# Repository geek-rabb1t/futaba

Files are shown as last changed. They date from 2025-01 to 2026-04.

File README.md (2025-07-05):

# Futaba

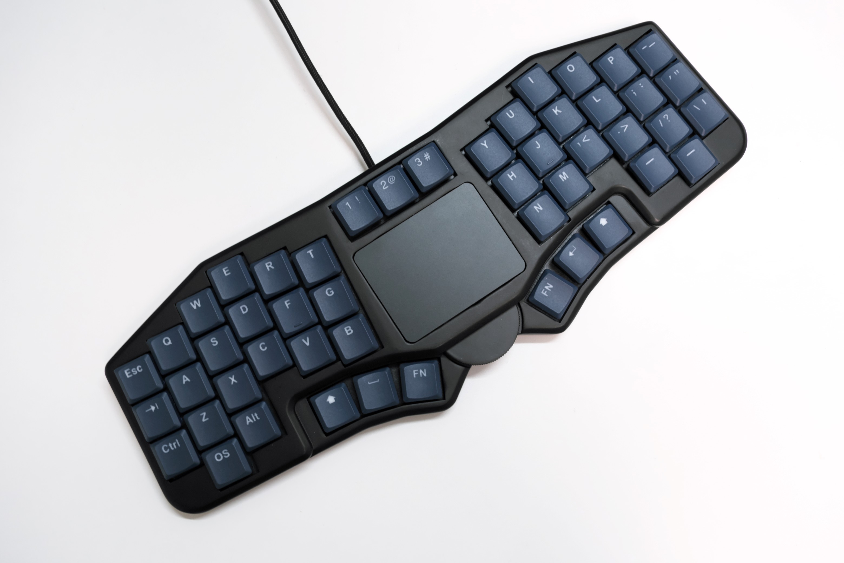
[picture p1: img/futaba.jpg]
Futaba


Futaba is a keyboard with trackpad.

## Features

- One-step-down thumb cluster that reduces fatigue even after long hours of work.
- Trackpad with multi-touch support for up to four fingers.
- Clickable giant wheel.
- Stack-mounted and flex-cut for the same feel on every key.
- Cable guides for easy use in tight spaces.

## Directory structure

This repository contains hardware design data only.

- Cases
    - 3D data of cases designed with FreeCAD.
    - It also contains stl files.
- Forms
    - Cut data of forms designed in Affinity Designer that can be ordered from Yousha Kobo.
- PCB
    - PCB data designed by KiCAD.

## About Firmware

QMK firmware or Vial firmware can be obtained from the following URL

- QMK Firmware
  - https://github.com/geek-rabb1t/qmk_firmware/tree/futaba
- Vial
  - https://github.com/geek-rabb1t/vial-qmk/tree/gr_master/keyboards/geek_rabb1t/futaba

## Build Guide

Please read here.

- https://geek-rabb1t.github.io/futaba/build_guide

---

# Futaba

Futaba

Futabaはトラックパッド付きキーボードです。

## 特徴

- 長時間の作業でも疲れにくい、一段下がった親指クラスタ。
- 4本指までのマルチタッチに対応したトラックパッド。
- クリック可能な巨大ホイール。
- スタックマウントとフレックスカットにより、どのキーも同じ打鍵感。
- 狭い場所でも使いやすいケーブルガイド。

## ディレクトリ構造

このリポジトリにはハードウェアの設計データのみ格納しています。

- case
    - FreeCADで設計したケースの3Dデータ。
    - stlファイルも含まれます。
- form
    - Affinity designerで設計した遊舎工房に発注可能なFormのカットデータ。
- pcb
    - KiCADで設計したPCBデータ。

## ファームウェアについて

以下のURLにQMK Firmwareもしくは、 Vialのファームウェアがあります。

- QMK Firmware
  - https://github.com/geek-rabb1t/qmk_firmware/tree/futaba
- Vial
  - https://github.com/geek-rabb1t/vial-qmk/tree/gr_master/keyboards/geek_rabb1t/futaba

## 組み立て手順

こちらをご覧ください。

- https://geek-rabb1t.github.io/futaba/build_guide

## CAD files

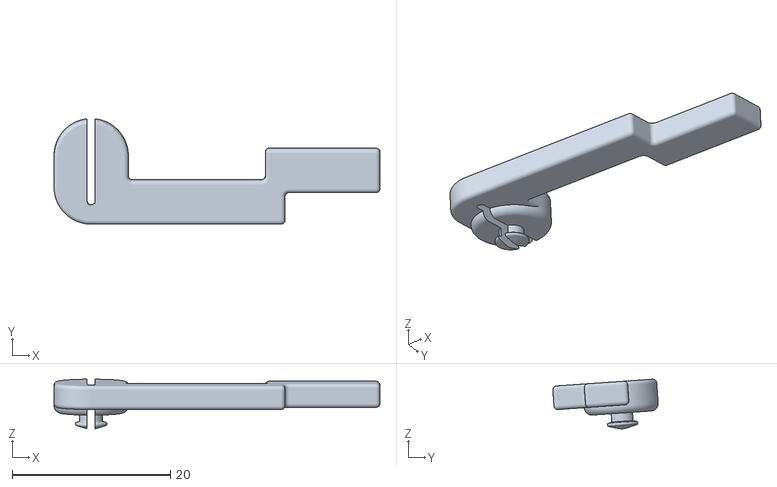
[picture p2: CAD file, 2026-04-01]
case/export/futaba-clicker_fdm.stl
41.2 x 13.3 x 6.27

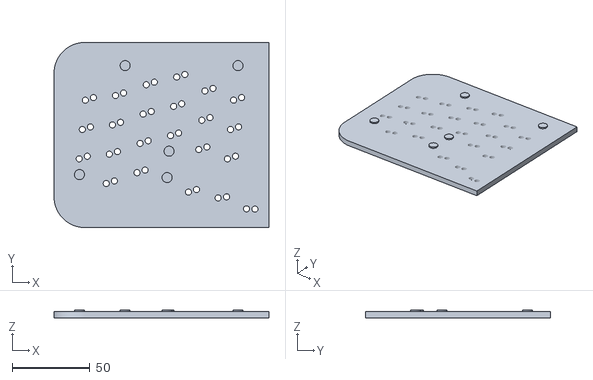
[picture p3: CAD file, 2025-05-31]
jig/soldering-jig-left-side.stl
138.6 x 119.4 x 5.00

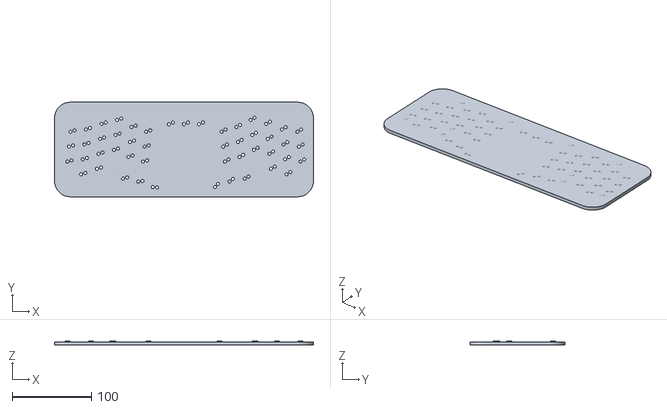
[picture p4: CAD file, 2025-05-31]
jig/soldering-jig-integrated.stl
327.0 x 119.4 x 5.00

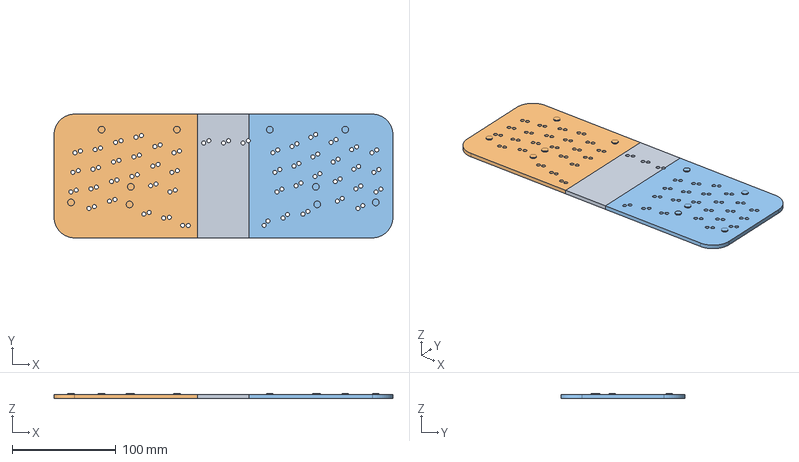
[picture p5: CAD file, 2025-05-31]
jig/soldering-jig.FCStd
327.0 x 119.4 x 5.00 mm
integrated
left-side
right-side

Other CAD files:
case/futaba-clicker.FCStd
jig/soldering-jig-right-side.stl

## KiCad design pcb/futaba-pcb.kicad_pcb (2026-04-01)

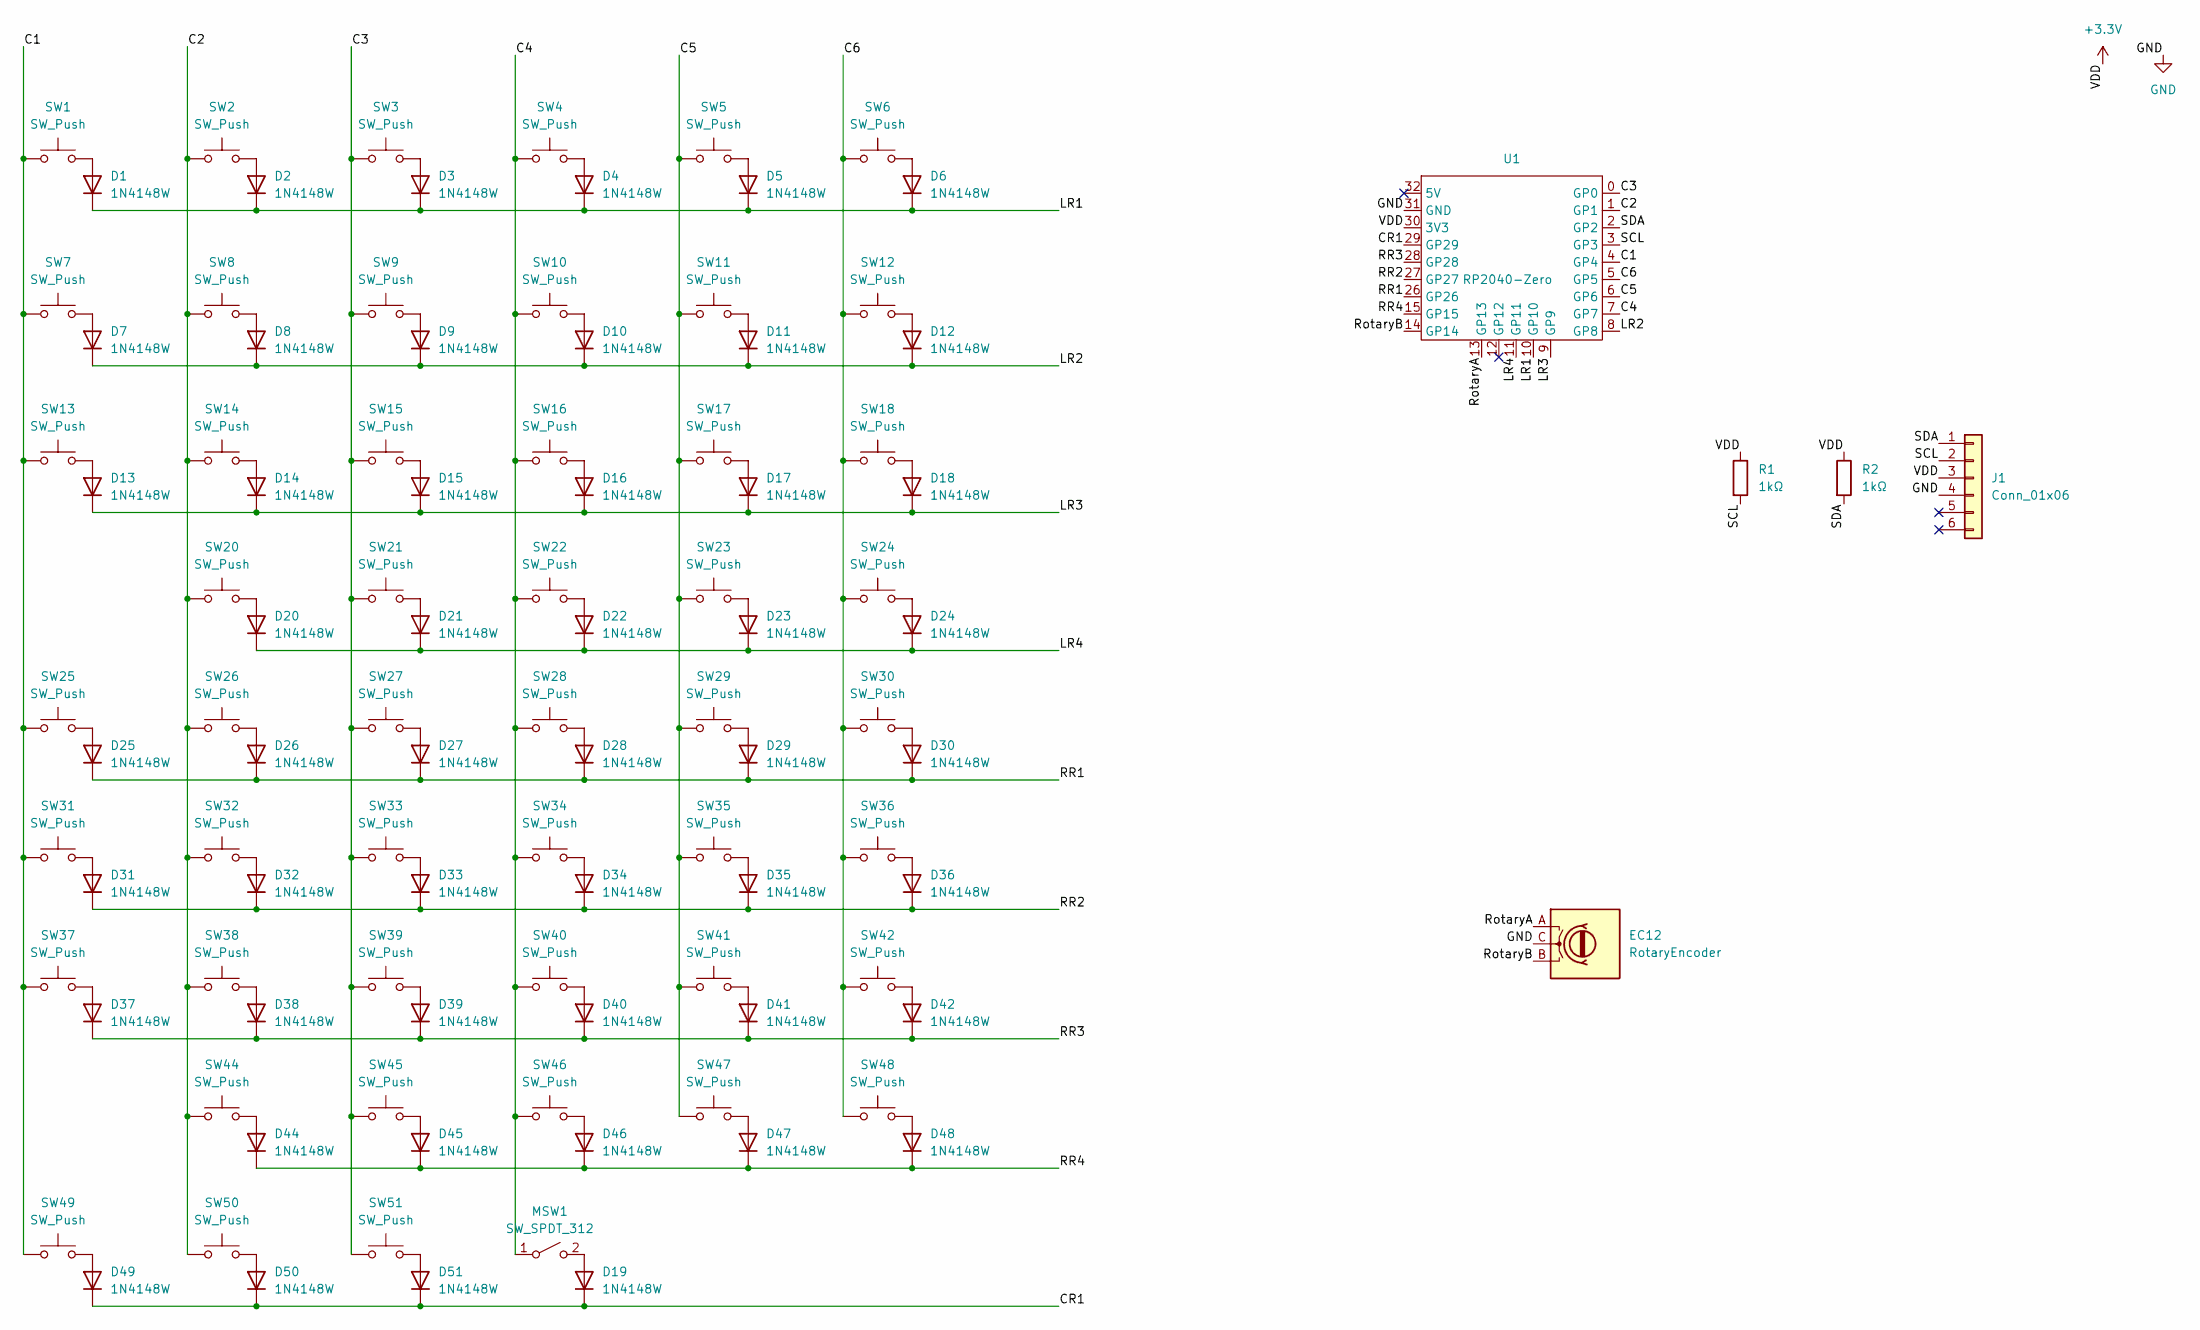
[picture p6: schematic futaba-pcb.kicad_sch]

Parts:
D1, D2, D3, D4, D5, D6, D7, D8, D9, D10, D11, D12, D13, D14, D15, D16, D17, D18, D19, D20, D21, D22, D23, D24, D25, D26, D27, D28, D29, D30, D31, D32, D33, D34, D35, D36, D37, D38, D39, D40, D41, D42, D44, D45, D46, D47, D48, D49, D50, D51: 1N4148W; D_SOD-123
EC12: RotaryEncoder; RotaryEncoder_Alps_EC12E_Vertical_H20mm
J1: Conn_01x06; Jushuo_AFC07-S06FCA-00_1x6-1MP_P0.50_Horizontal-JLC; LCSC Part # C11048
MSW1: SW_SPDT_312; MicroSwitch; Part Name D2F-01FL2-A
R1, R2: 1kΩ; R_0603_1608Metric
SW1, SW2, SW3, SW4, SW5, SW6, SW25, SW26, SW27, SW28, SW29, SW30, SW49, SW50, SW51: SW_Push; Choc_Socket-flex-drill_top
SW7, SW8, SW9, SW10, SW11, SW12, SW13, SW14, SW15, SW16, SW17, SW18, SW31, SW32, SW33, SW34, SW35, SW36, SW37, SW38, SW39, SW40, SW41: SW_Push; Choc_Socket-flex-drill
SW20, SW21, SW42, SW44, SW45: SW_Push; Choc_Socket-flex-drill_bottom
SW22, SW23, SW24, SW46, SW47, SW48: SW_Push; Choc_Socket-flex-drill_mid
U1: RP2040-Zero

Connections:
+3.3V: J1.3, R1.1, R2.1, U1.30 (3V3)
/C1: SW1.1, SW7.1, SW13.1, SW25.1, SW31.1, SW37.1, SW49.1, U1.4 (GP4)
/C2: SW2.1, SW8.1, SW14.1, SW20.1, SW26.1, SW32.1, SW38.1, SW44.1, SW50.1, U1.1 (GP1)
/C3: SW3.1, SW9.1, SW15.1, SW21.1, SW27.1, SW33.1, SW39.1, SW45.1, SW51.1, U1.0 (GP0)
/C4: MSW1.1 (A), SW4.1, SW10.1, SW16.1, SW22.1, SW28.1, SW34.1, SW40.1, SW46.1, U1.7 (GP7)
/C5: SW5.1, SW11.1, SW17.1, SW23.1, SW29.1, SW35.1, SW41.1, SW47.1, U1.6 (GP6)
/C6: SW6.1, SW12.1, SW18.1, SW24.1, SW30.1, SW36.1, SW42.1, SW48.1, U1.5 (GP5)
/CR1: D19.1 (K), D49.1 (K), D50.1 (K), D51.1 (K), U1.29 (GP29)
/LR1: D1.1 (K), D2.1 (K), D3.1 (K), D4.1 (K), D5.1 (K), D6.1 (K), U1.10 (GP10)
/LR2: D7.1 (K), D8.1 (K), D9.1 (K), D10.1 (K), D11.1 (K), D12.1 (K), U1.8 (GP8)
/LR3: D13.1 (K), D14.1 (K), D15.1 (K), D16.1 (K), D17.1 (K), D18.1 (K), U1.9 (GP9)
/LR4: D20.1 (K), D21.1 (K), D22.1 (K), D23.1 (K), D24.1 (K), U1.11 (GP11)
/RR1: D25.1 (K), D26.1 (K), D27.1 (K), D28.1 (K), D29.1 (K), D30.1 (K), U1.26 (GP26)
/RR2: D31.1 (K), D32.1 (K), D33.1 (K), D34.1 (K), D35.1 (K), D36.1 (K), U1.27 (GP27)
/RR3: D37.1 (K), D38.1 (K), D39.1 (K), D40.1 (K), D41.1 (K), D42.1 (K), U1.28 (GP28)
/RR4: D44.1 (K), D45.1 (K), D46.1 (K), D47.1 (K), D48.1 (K), U1.15 (GP15)
/RotaryA: EC12.A, U1.13 (GP13)
/RotaryB: EC12.B, U1.14 (GP14)
/SCL: J1.2, R1.2, U1.3 (GP3)
/SDA: J1.1, R2.2, U1.2 (GP2)
GND: EC12.C, J1.4, U1.31 (GND)
unnamed: D1.2 (A), SW1.2
unnamed: D2.2 (A), SW2.2
unnamed: D3.2 (A), SW3.2
unnamed: D4.2 (A), SW4.2
unnamed: D5.2 (A), SW5.2
unnamed: D6.2 (A), SW6.2
unnamed: D7.2 (A), SW7.2
unnamed: D8.2 (A), SW8.2
unnamed: D9.2 (A), SW9.2
unnamed: D10.2 (A), SW10.2
unnamed: D11.2 (A), SW11.2
unnamed: D12.2 (A), SW12.2
unnamed: D13.2 (A), SW13.2
unnamed: D14.2 (A), SW14.2
unnamed: D15.2 (A), SW15.2
unnamed: D16.2 (A), SW16.2
unnamed: D17.2 (A), SW17.2
unnamed: D18.2 (A), SW18.2
unnamed: D19.2 (A), MSW1.2 (B)
unnamed: D20.2 (A), SW20.2
unnamed: D21.2 (A), SW21.2
unnamed: D22.2 (A), SW22.2
unnamed: D23.2 (A), SW23.2
unnamed: D24.2 (A), SW24.2
unnamed: D25.2 (A), SW25.2
unnamed: D26.2 (A), SW26.2
unnamed: D27.2 (A), SW27.2
unnamed: D28.2 (A), SW28.2
unnamed: D29.2 (A), SW29.2
unnamed: D30.2 (A), SW30.2
unnamed: D31.2 (A), SW31.2
unnamed: D32.2 (A), SW32.2
unnamed: D33.2 (A), SW33.2
unnamed: D34.2 (A), SW34.2
unnamed: D35.2 (A), SW35.2
unnamed: D36.2 (A), SW36.2
unnamed: D37.2 (A), SW37.2
unnamed: D38.2 (A), SW38.2
unnamed: D39.2 (A), SW39.2
unnamed: D40.2 (A), SW40.2
unnamed: D41.2 (A), SW41.2
unnamed: D42.2 (A), SW42.2
unnamed: D44.2 (A), SW44.2
unnamed: D45.2 (A), SW45.2
unnamed: D46.2 (A), SW46.2
unnamed: D47.2 (A), SW47.2
unnamed: D48.2 (A), SW48.2
unnamed: D49.2 (A), SW49.2
unnamed: D50.2 (A), SW50.2
unnamed: D51.2 (A), SW51.2

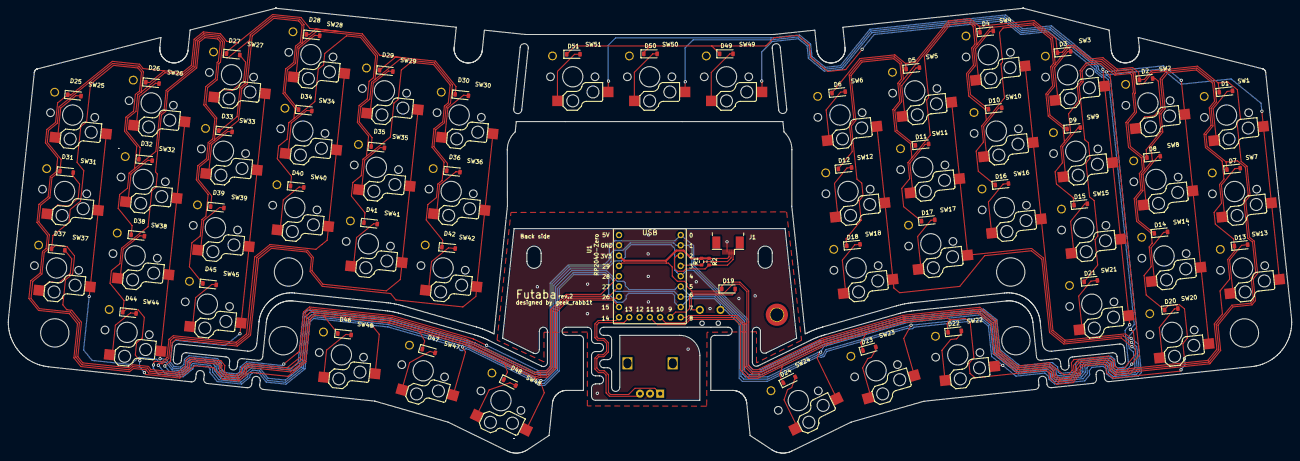
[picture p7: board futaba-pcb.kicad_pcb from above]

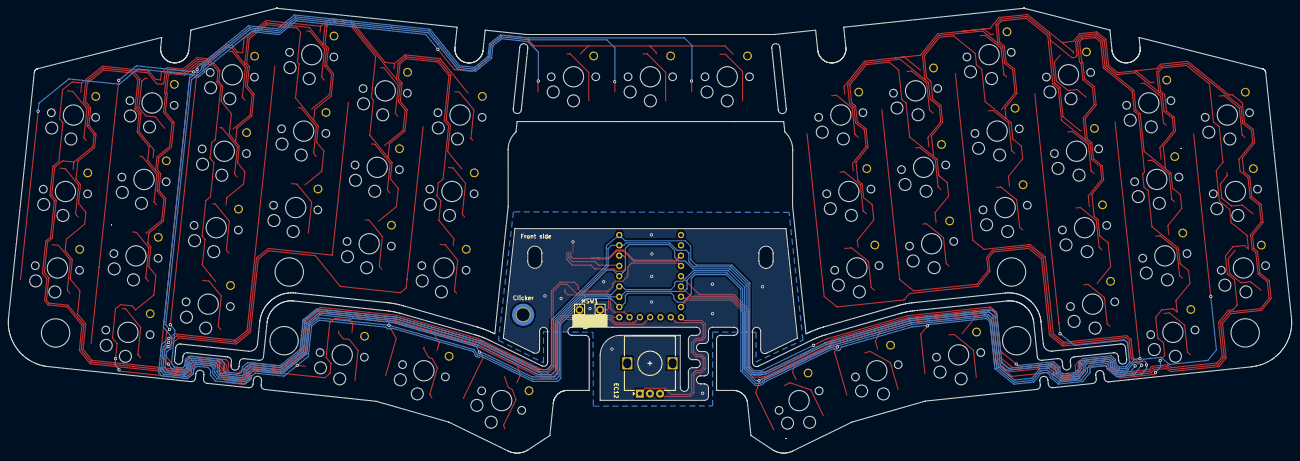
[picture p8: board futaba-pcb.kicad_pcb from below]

Board: 2 copper layers, 317.2 x 109.9 mm, 106 parts (2 on the bottom side), 71 nets.

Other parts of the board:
Clicker: MountingHole_3.2mm_M3_ISO14580_Pad_TopBottom

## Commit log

2023-12-19 add ignore files
    [futaba-BodyPad007-v2.stl, futaba-BodyPad007.stl, futaba-bottom.stl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]
2024-07-26 update 3d model
    [futaba-BodyPad007-v2.stl, futaba-BodyPad007.stl, futaba-bottom.stl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]
2024-07-26 Add kicad data
    [futaba-pcb.kicad_pcb, futaba-pcb.kicad_sch]
2024-08-25 Update pcb data
    [futaba-pcb.kicad_pcb, futaba-pcb.kicad_sch]
2024-11-13 move pcb folder
    [futaba-pcb.kicad_pcb, futaba-pcb.kicad_sch]
2024-11-13 Update form laser cutting data
2024-11-13 Update case data
2024-11-19 Update case data.
2024-11-19 Update pcb outline.
    [futaba-pcb.kicad_pcb]
2025-01-11 Update case design
2025-03-02 Fix bottom of case
2025-05-31 add soldering jig
    [soldering-jig-integrated.stl, soldering-jig-left-side.stl, soldering-jig-right-side.stl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]
2026-04-01 improve clicker for fdm
    [futaba-clicker.FCStd, futaba-clicker_fdm.stl]
2026-04-01 add microswitch adapter
    [smd-microswitch-adapter.kicad_pcb, smd-microswitch-adapter.kicad_sch]
2026-04-01 update pcb
    [futaba-pcb.kicad_pcb, futaba-pcb.kicad_sch]
